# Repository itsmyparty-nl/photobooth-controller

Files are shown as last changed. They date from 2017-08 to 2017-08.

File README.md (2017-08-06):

# Photobooth Controller #

The hardware side of the photobooth

### What is this repository for? ###

* PCB Board & Corresponding Firmware to handle hardware buttons and lights for the photobooth 

### How do I get set up? ###

* Install Arduino
* Select correct library folder

### Contribution guidelines ###

* Writing tests
* Code review
* Other guidelines

### Who do I talk to? ###

* Patrick@itsmyparty.nl

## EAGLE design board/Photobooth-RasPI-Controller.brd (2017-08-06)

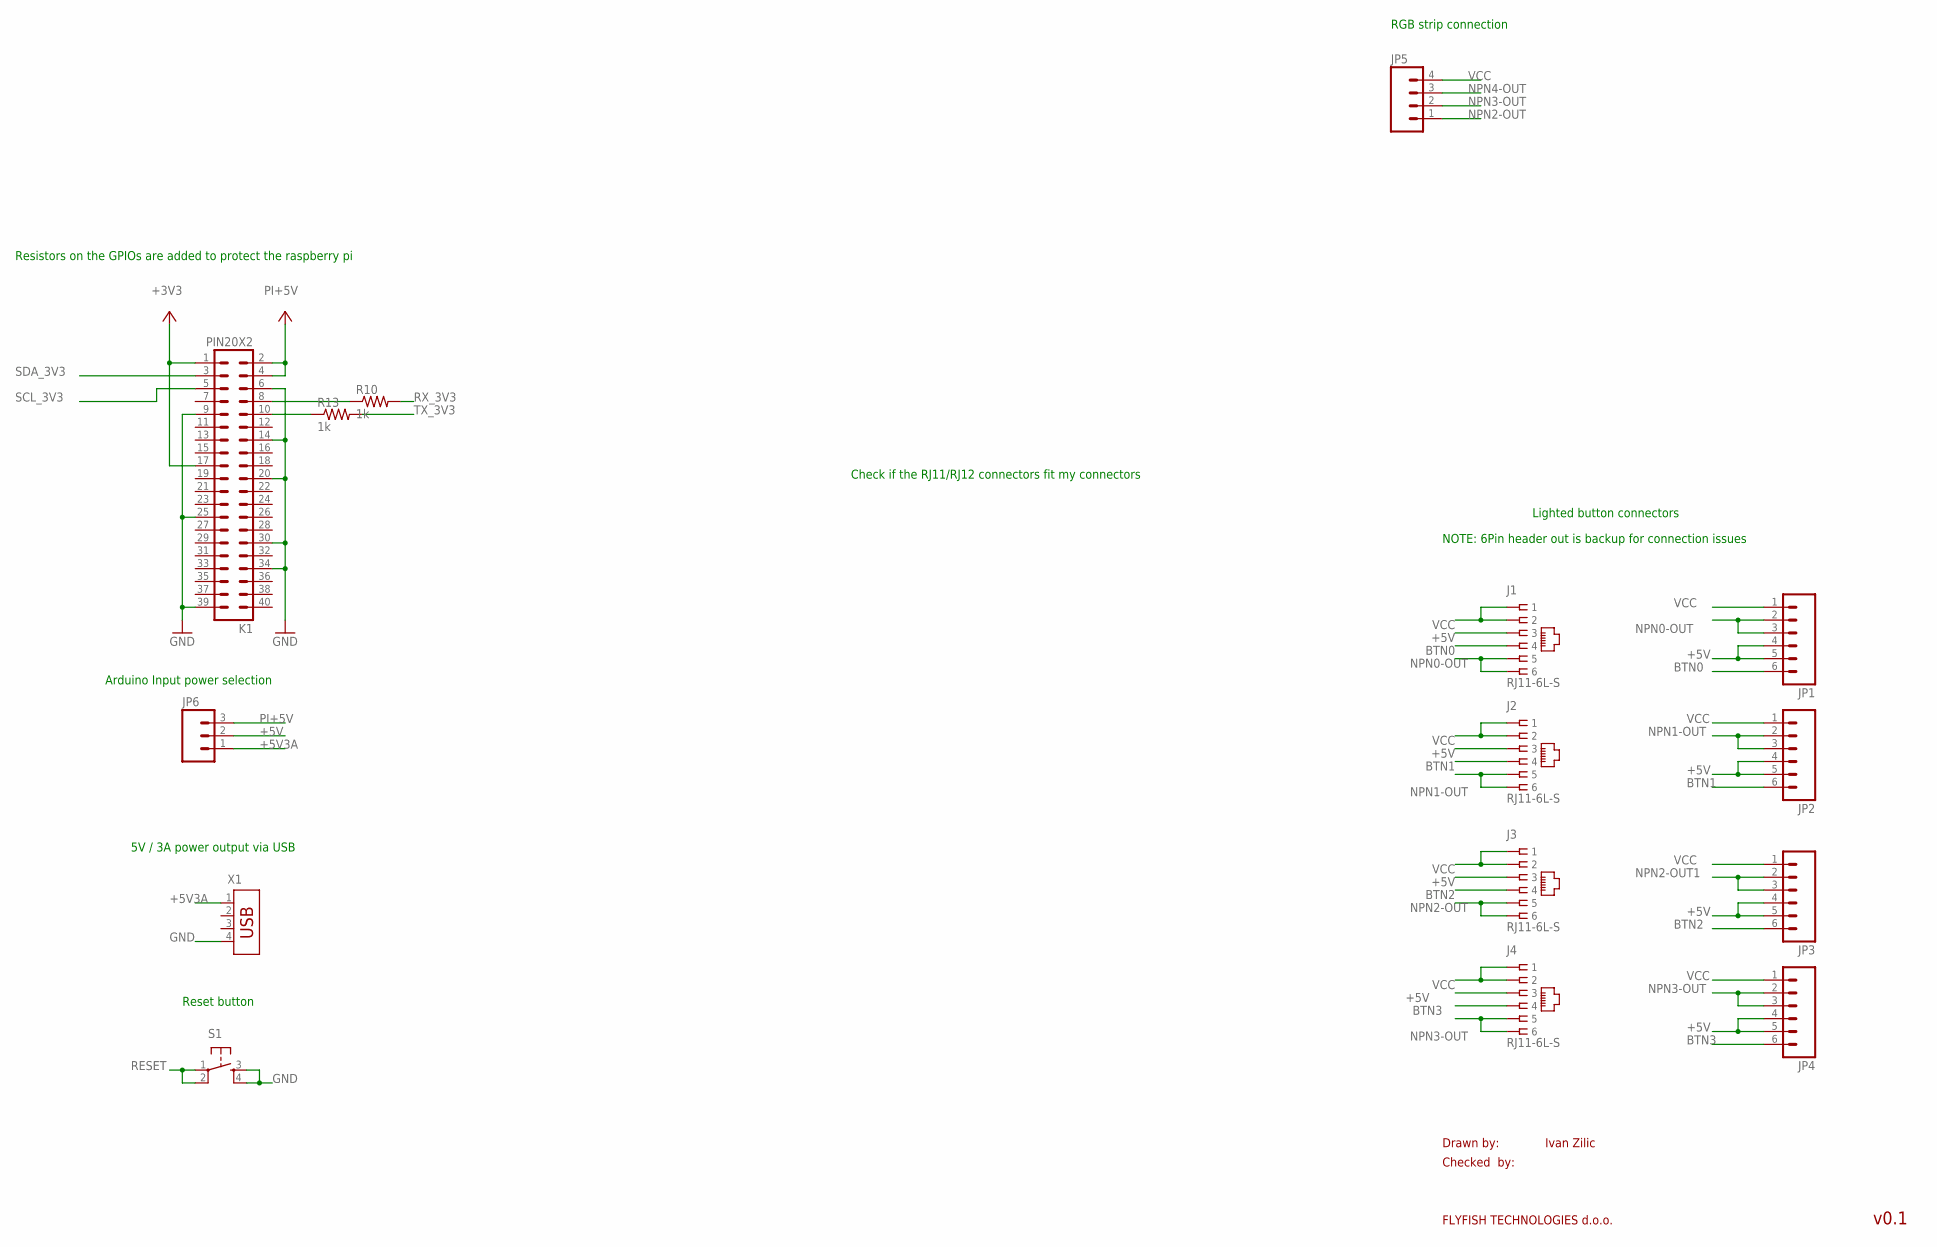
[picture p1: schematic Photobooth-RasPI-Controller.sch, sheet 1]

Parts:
J1, J2, J3, J4: RJ11-6L-S; RJ11-NO_SHIELD
JP1, JP2, JP3, JP4: M06LOCK; 1X06_LOCK
JP5: M04LOCK; 1X04_LOCK
JP6: M03LOCK; 1X03_LOCK
K1: PIN20X2; PIN_20X2
R10, R13: 1k; 0805
S1: TAC_SWITCHPTH; TACTILE-PTH
X1: USB-787616; USB

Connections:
+3V3: K1.1, K1.17; also elsewhere on the board
+5V: J1.3, J2.3, J3.3, J4.3, JP1.4, JP1.5, JP2.4, JP2.5, JP3.4, JP3.5, JP4.4, JP4.5, JP6.2; also elsewhere on the board
+5V3A: JP6.1, X1.1; also elsewhere on the board
BTN0: J1.4, JP1.6; also elsewhere on the board
BTN1: J2.4, JP2.6; also elsewhere on the board
BTN2: J3.4, JP3.6; also elsewhere on the board
BTN3: J4.4, JP4.6; also elsewhere on the board
GND: K1.6, K1.9, K1.14, K1.20, K1.25, K1.30, K1.34, K1.39, S1.3, S1.4, X1.4; also elsewhere on the board
unnamed: K1.8, R10.1
unnamed: K1.10, R13.1
NPN0-OUT: J1.5, J1.6, JP1.2, JP1.3; also elsewhere on the board
NPN1-OUT: J2.5, J2.6, JP2.2, JP2.3; also elsewhere on the board
NPN2-OUT: J3.5, J3.6, JP5.1; also elsewhere on the board
NPN2-OUT1: JP3.2, JP3.3
NPN3-OUT: J4.5, J4.6, JP4.2, JP4.3, JP5.2; also elsewhere on the board
NPN4-OUT: JP5.3; also elsewhere on the board
PI+5V: JP6.3, K1.2, K1.4
RESET: S1.1, S1.2; also elsewhere on the board
RX_3V3: R10.2; also elsewhere on the board
SCL_3V3: K1.5; also elsewhere on the board
SDA_3V3: K1.3; also elsewhere on the board
TX_3V3: R13.2; also elsewhere on the board
VCC: J1.1, J1.2, J2.1, J2.2, J3.1, J3.2, J4.1, J4.2, JP1.1, JP2.1, JP3.1, JP4.1, JP5.4; also elsewhere on the board

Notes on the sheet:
Drawn by:
Checked by:
FLYFISH TECHNOLOGIES d.o.o.
Ivan Zilic
v0.1
5V / 3A power output via USB
Resistors on the GPIOs are added to protect the raspberry pi
Check if the RJ11/RJ12 connectors fit my connectors
RGB strip connection
Lighted button connectors
NOTE: 6Pin header out is backup for connection issues
Arduino Input power selection
Reset button

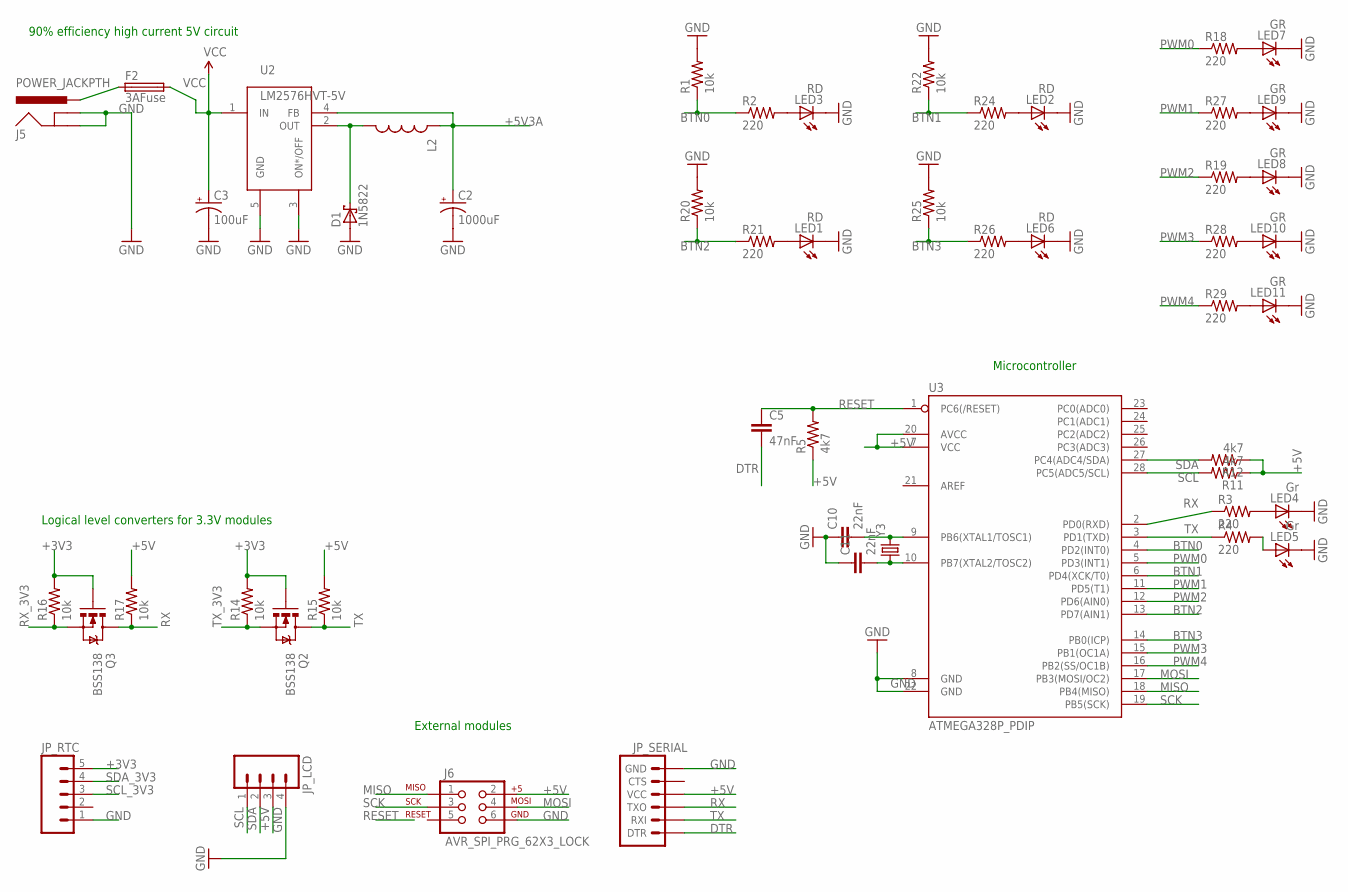
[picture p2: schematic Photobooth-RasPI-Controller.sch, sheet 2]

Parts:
C2: 1000uF; CPOL-RADIAL-1000UF-25V
C3: 100uF; CPOL-RADIAL-100UF-25V
C5: 47nF; CAP-PTH-SMALL
C10, C11: 22nF; CAP-PTH-SMALL
D1: 1N5822; C4111-15
F2: 3AFuse; LITTLEFUSE
J5: POWER_JACKPTH; POWER_JACK_PTH
J6: AVR_SPI_PRG_62X3_LOCK; 2X3_LOCK
JP_LCD: M04PTH; 1X04
JP_RTC: M05LOCK; 1X05_LOCK
JP_SERIAL: ARDUINO_SERIAL_PROGRAMLOCK; 1X06_LOCK
L2: INDUCTORRLB0912; RLB0912
LED1, LED2, LED3, LED6: RD; CHIP-LED0805
LED4, LED5: Gr; CHIP-LED0805
LED7, LED8, LED9, LED10, LED11: GR; CHIP-LED0805
Q2, Q3: BSS138; SOT23-3
R1, R14, R15, R16, R17, R20, R22, R25: 10k; 0805
R2, R3, R4, R18, R19, R21, R24, R26, R27, R28, R29: 220; 0805
R5, R11, R12: 4k7; 0805
U2: LM2576HVT-5V; LM2576
U3: ATMEGA328P_PDIP; DIL28-3
Y3: CRYSTALHC49UV; HC49U-V

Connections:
+3V3: JP_RTC.5, Q2.1 (G), Q3.1 (G), R14.2, R16.2; also elsewhere on the board
+5V: J6.2, JP_LCD.3, JP_SERIAL.4 (VCC), R5.1, R11.1, R12.1, R15.2, R17.2, U3.7 (VCC), U3.20 (AVCC); also elsewhere on the board
+5V3A: C2.+, L2.1, U2.4 (FB); also elsewhere on the board
BTN0: R1.1, R2.1, U3.4 (PD2(INT0)); also elsewhere on the board
BTN1: R22.1, R24.1, U3.6 (PD4(XCK/T0)); also elsewhere on the board
BTN2: R20.1, R21.1, U3.13 (PD7(AIN1)); also elsewhere on the board
BTN3: R25.1, R26.1, U3.14 (PB0(ICP)); also elsewhere on the board
DTR: C5.2, JP_SERIAL.1 (DTR)
GND: C2.-, C3.2 (-), C10.1, C11.1, D1.A, J5.GND, J5.GNDBREAK, J6.6, JP_LCD.4, JP_RTC.1, JP_SERIAL.6 (GND), LED1.C, LED2.C, LED3.C, LED4.C, LED5.C, LED6.C, LED7.C, LED8.C, LED9.C, LED10.C, LED11.C, R1.2, R20.2, R22.2, R25.2, U2.3 (ON*/OFF), U2.5 (GND), U3.8 (GND), U3.22 (GND); also elsewhere on the board
MISO: J6.1, U3.18 (PB4(MISO))
MOSI: J6.4, U3.17 (PB3(MOSI/OC2))
unnamed: C11.2, U3.10 (PB7(XTAL2/TOSC2)), Y3.1
unnamed: C10.2, U3.9 (PB6(XTAL1/TOSC1)), Y3.2
unnamed: D1.C, L2.2, U2.2 (OUT)
unnamed: LED7.A, R18.2
unnamed: LED8.A, R19.2
unnamed: LED1.A, R21.2
unnamed: LED2.A, R24.2
unnamed: LED6.A, R26.2
unnamed: LED9.A, R27.2
unnamed: LED10.A, R28.2
unnamed: LED11.A, R29.2
unnamed: F2.1, J5.PWR
unnamed: LED3.A, R2.2
unnamed: LED4.A, R3.2
unnamed: LED5.A, R4.2
PWM0: R18.1, U3.5 (PD3(INT1)); also elsewhere on the board
PWM1: R27.1, U3.11 (PD5(T1)); also elsewhere on the board
PWM2: R19.1, U3.12 (PD6(AIN0)); also elsewhere on the board
PWM3: R28.1, U3.15 (PB1(OC1A)); also elsewhere on the board
PWM4: R29.1, U3.16 (PB2(SS/OC1B)); also elsewhere on the board
RESET: C5.1, R5.2, U3.1 (PC6(/RESET)); also elsewhere on the board
RX: JP_SERIAL.3 (TXO), Q3.3 (D), R3.1, R17.1, U3.2 (PD0(RXD))
RX_3V3: Q3.2 (S), R16.1; also elsewhere on the board
SCK: J6.3, U3.19 (PB5(SCK))
SCL: JP_LCD.1, R11.2, U3.28 (PC5(ADC5/SCL))
SCL_3V3: JP_RTC.3; also elsewhere on the board
SDA: JP_LCD.2, R12.2, U3.27 (PC4(ADC4/SDA))
SDA_3V3: JP_RTC.4; also elsewhere on the board
TX: JP_SERIAL.2 (RXI), Q2.3 (D), R4.1, R15.1, U3.3 (PD1(TXD))
TX_3V3: Q2.2 (S), R14.1; also elsewhere on the board
VCC: C3.1 (+), F2.2, U2.1 (IN); also elsewhere on the board

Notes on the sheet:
Logical level converters for 3.3V modules
External modules
90% efficiency high current 5V circuit
Microcontroller

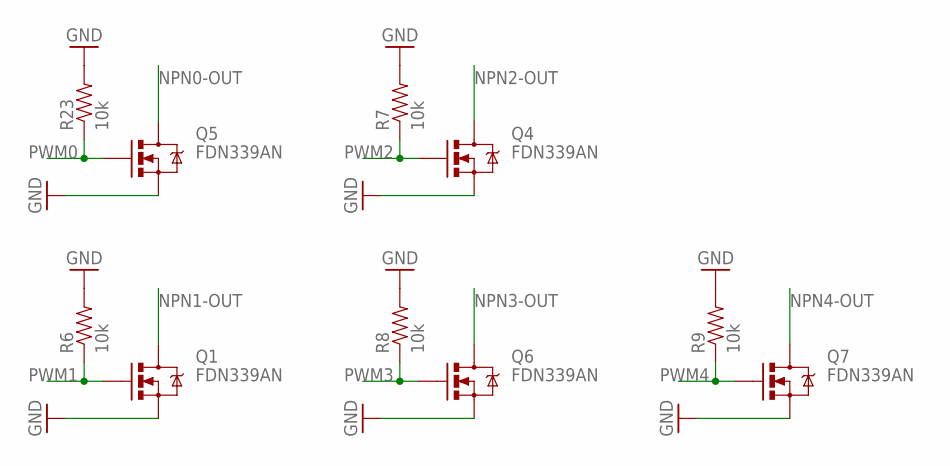
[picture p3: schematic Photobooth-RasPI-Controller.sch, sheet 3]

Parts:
Q1, Q4, Q5, Q6, Q7: FDN339AN; SOT23-3
R6, R7, R8, R9, R23: 10k; 0805

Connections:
GND: Q1.2 (S), Q4.2 (S), Q5.2 (S), Q6.2 (S), Q7.2 (S), R6.2, R7.2, R8.2, R9.2, R23.2; also elsewhere on the board
NPN0-OUT: Q5.3 (D); also elsewhere on the board
NPN1-OUT: Q1.3 (D); also elsewhere on the board
NPN2-OUT: Q4.3 (D); also elsewhere on the board
NPN3-OUT: Q6.3 (D); also elsewhere on the board
NPN4-OUT: Q7.3 (D); also elsewhere on the board
PWM0: Q5.1 (G), R23.1; also elsewhere on the board
PWM1: Q1.1 (G), R6.1; also elsewhere on the board
PWM2: Q4.1 (G), R7.1; also elsewhere on the board
PWM3: Q6.1 (G), R8.1; also elsewhere on the board
PWM4: Q7.1 (G), R9.1; also elsewhere on the board

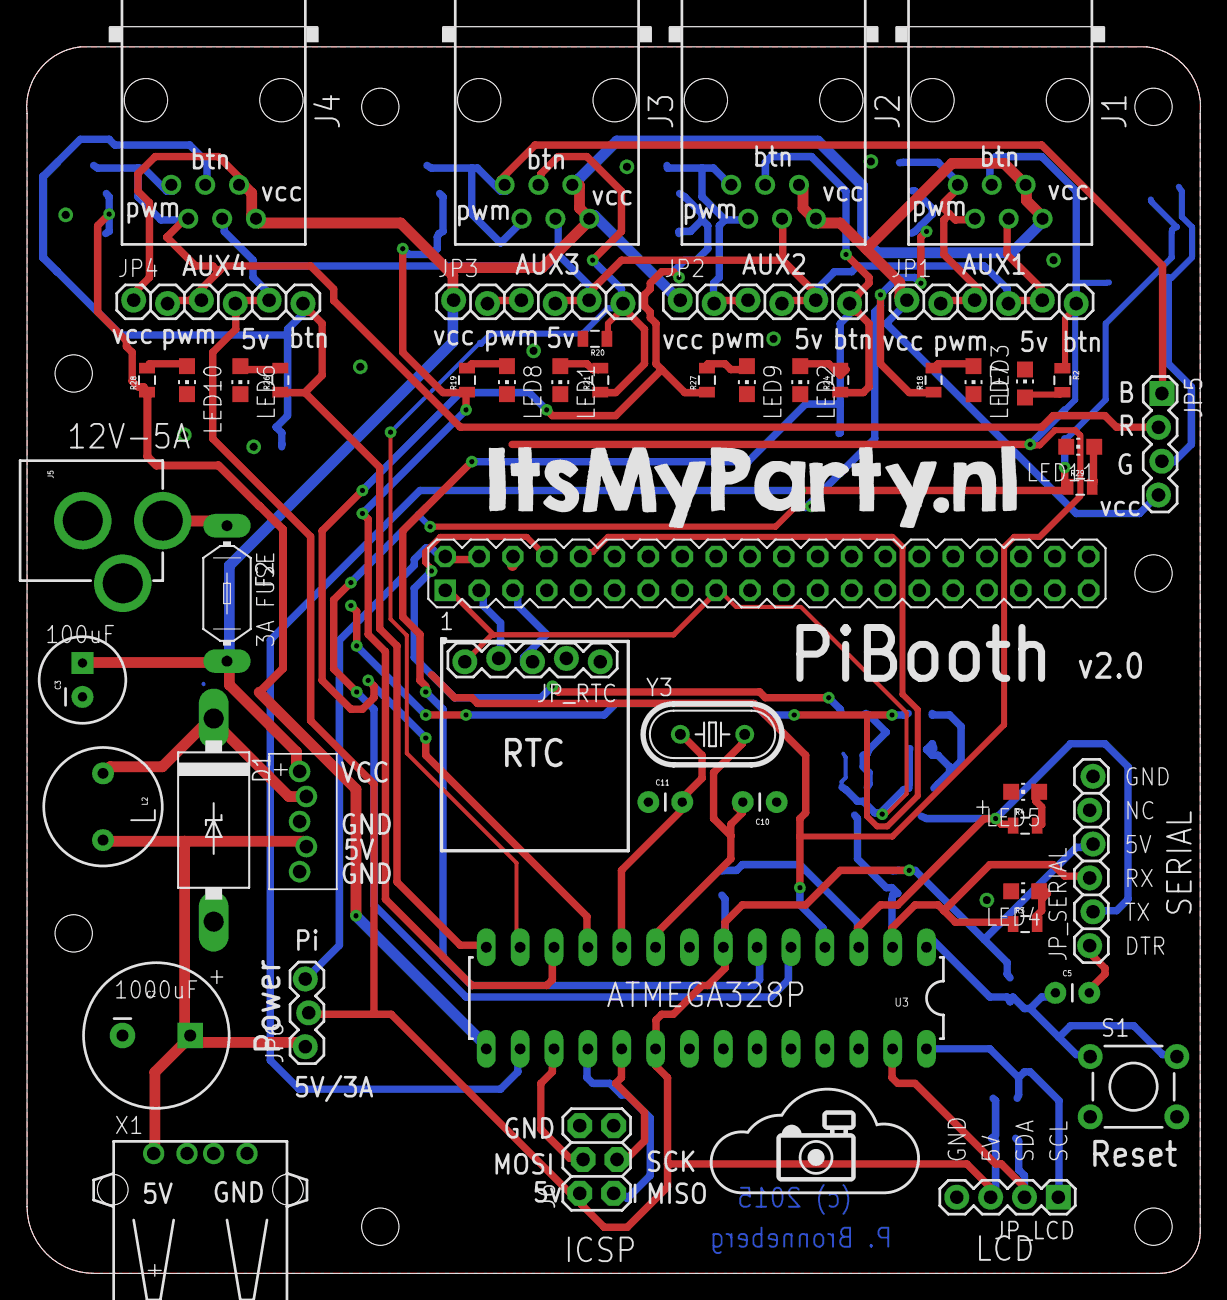
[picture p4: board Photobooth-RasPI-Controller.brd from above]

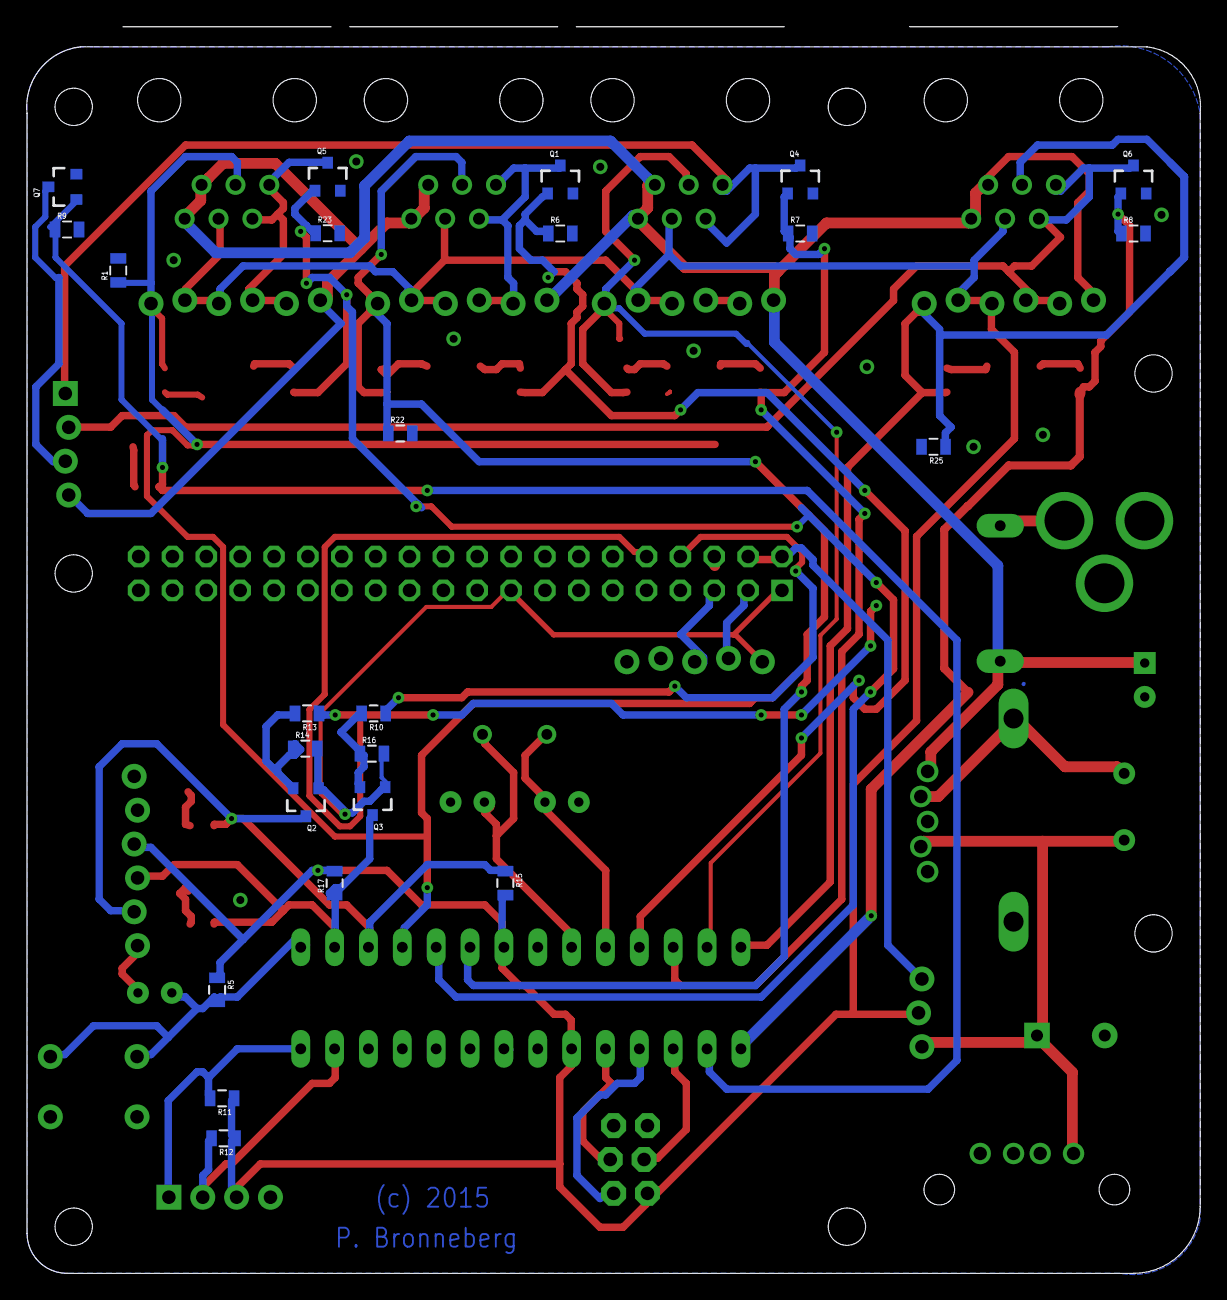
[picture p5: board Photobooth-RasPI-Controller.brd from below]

Board: 2 copper layers, 88.0 x 93.5 mm, 76 parts (24 on the bottom side), 51 nets.

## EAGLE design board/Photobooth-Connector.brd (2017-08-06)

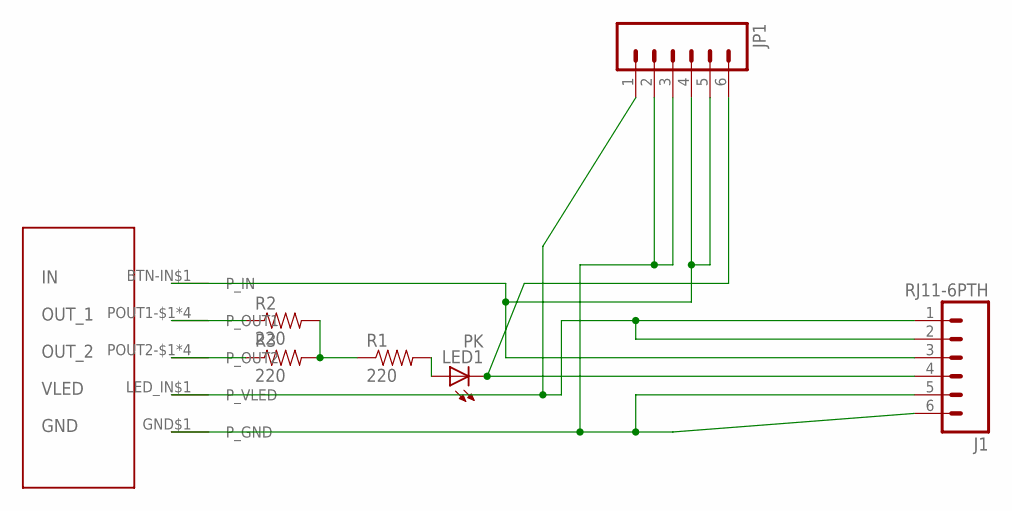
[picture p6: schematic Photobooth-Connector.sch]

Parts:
J1: RJ11-6PTH; RJ11-6
JP1: M06LOCK; 1X06_LOCK
LED1: PK; CHIP-LED0805
R1, R2, R3: 220; 0805
U$1: KERMIS_BUTTON; SLOT_DRILLED

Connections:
unnamed: J1.3, JP1.4, JP1.5, U$1.BTN-IN$1 (P_IN)
unnamed: J1.4, JP1.6, LED1.C
unnamed: R1.1, R2.2, R3.2
unnamed: LED1.A, R1.2
unnamed: J1.1, J1.2, JP1.1, U$1.LED_IN$1 (P_VLED)
unnamed: J1.5, J1.6, JP1.2, JP1.3, U$1.GND$1 (P_GND)
unnamed: R2.1, U$1.POUT1-$1 (P_OUT1), U$1.POUT1-$2 (P_OUT1), U$1.POUT1-$3 (P_OUT1), U$1.POUT1-$4 (P_OUT1)
unnamed: R3.1, U$1.POUT2-$1 (P_OUT2), U$1.POUT2-$2 (P_OUT2), U$1.POUT2-$3 (P_OUT2), U$1.POUT2-$4 (P_OUT2)

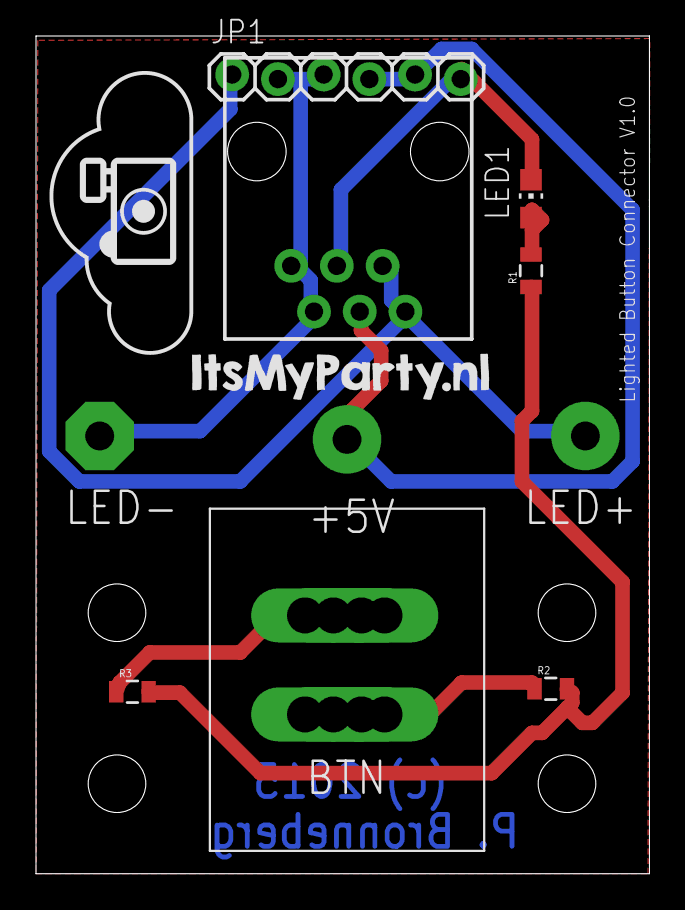
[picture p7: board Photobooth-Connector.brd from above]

Board: 2 copper layers, 34.1 x 46.5 mm, 7 parts (0 on the bottom side), 8 nets.

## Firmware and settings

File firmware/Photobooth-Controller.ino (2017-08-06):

// *** PhotoboothController ***
// Control the photobooth by supplying buttons which can be armed and released,
// which send commands to the application via a serial interface and the
// CmdMessenger library
// Based on the ArduinoController example

#include <CmdMessenger.h>  // CmdMessenger
#include <SoftTimer.h>
#include <Heartbeat.h>
#include <BlinkTask.h>
#include <SoftPwmTask.h>
#include <Dimmer.h>

// status heartbeat led variables 
const int ledPin            = 13;  // Pin of internal Led
bool ledState               = 1;   // Current state of Led

bool triggerBtnPushed = false;
bool printBtnPushed = false;
bool printTwiceBtnPushed = false;
bool powerBtnPushed = false;

#define INPUT_PIN_1 2
#define INPUT_PIN_2 4
#define INPUT_PIN_3 7
#define INPUT_PIN_4 8

/* In this demonstration a pulsating is implemented. */
#define OUT_PIN_1  3
#define OUT_PIN_2  5
#define OUT_PIN_3  6
#define OUT_PIN_4  9

#define triggerBtnLed  OUT_PIN_1
#define powerBtnLed  OUT_PIN_4
#define printBtnLed  OUT_PIN_2
#define printTwiceBtnLed  OUT_PIN_3

#define triggerBtnPin  INPUT_PIN_1
#define powerBtnPin  INPUT_PIN_4
#define printBtnPin  INPUT_PIN_2
#define printTwiceBtnPin  INPUT_PIN_3

Task buttonTaskTrigger(110, buttonReadTrigger);
Task buttonTaskPrint(80, buttonReadPrint);
Task buttonTaskPrintTwice(120, buttonReadPrintTwice);
Task buttonTaskPower(90, buttonReadPower);
Task commandHandlerTask(500, readSerial);

Heartbeat triggerLedTask(triggerBtnLed);
BlinkTask printLedTask(printBtnLed,1000);
BlinkTask printTwiceLedTask(printTwiceBtnLed,1000);
BlinkTask powerLedTask(powerBtnLed,1000);

//SoftPwmTask triggerLockedLedTask(triggerBtnLed);
//SoftPwmTask printLockedLedTask(printBtnLed);
//SoftPwmTask printTwiceLockedLedTask(printTwiceBtnLed);
//SoftPwmTask powerLockedLedTask(powerBtnLed);
//Dimmer triggerLockedDimmer(&triggerLockedLedTask, 1500);
//Dimmer printLockedDimmer(&printLockedLedTask, 1500);
//Dimmer printTwiceLockedDimmer(&printTwiceLockedLedTask, 1500);
//Dimmer powerLockedDimmer(&powerLockedLedTask, 1500);

// Attach a new CmdMessenger object to the default Serial port
CmdMessenger cmdMessenger = CmdMessenger(Serial);

// This is the list of recognized commands. These kcan be commands that can either be sent or received. 
// In order to receive, attach a callback function to these events
enum
{
  kAcknowledge,
  kError,
  kTrigger,
  kPrint,
  kPower,
  kPrepareControl,
  kReleaseControl,
  kPrintTwice,
  kLockControl,
  kUnlockControl,
  kInitialize
};

// Callbacks define on which received commands we take action
void attachCommandCallbacks()
{
  // Attach callback methods
  cmdMessenger.attach(OnUnknownCommand);
  cmdMessenger.attach(kPrepareControl, OnPrepareControl);
  cmdMessenger.attach(kReleaseControl, OnReleaseControl);
  cmdMessenger.attach(kLockControl, OnLockControl);
  cmdMessenger.attach(kUnlockControl, OnLockControl);
  cmdMessenger.attach(kInitialize, Initialize);
}

// Called when a received command has no attached function
void OnUnknownCommand()
{
  cmdMessenger.sendCmd(kError,"Command without attached callback");
}

// Initialize all controls to a ready state
void Initialize()
{
  // Remove all tasks, since the UDOO arduino has persistent state
  SoftTimer.remove(&buttonTaskPrintTwice);
  SoftTimer.remove(&printTwiceLedTask);
  SoftTimer.remove(&buttonTaskPrint);
  SoftTimer.remove(&printLedTask);
  SoftTimer.remove(&buttonTaskTrigger);
  SoftTimer.remove(&triggerLedTask);
  SoftTimer.remove(&buttonTaskPower);
  
  // Also stop all dimmers
  //triggerLockedDimmer.off();
  //powerLockedDimmer.off();
  //printLockedDimmer.off();
  //printTwiceLockedDimmer.off();
 
  //Set all pins low to check connections
  digitalWrite(OUT_PIN_1, LOW);
  digitalWrite(OUT_PIN_2, LOW);
  digitalWrite(OUT_PIN_3, LOW);
  digitalWrite(OUT_PIN_4, LOW);
}

// Callback function that sets led on or off
void OnLockControl()
{
  int control;
  // Read led state argument, interpret string as int
  control = cmdMessenger.readIntArg();
  switch (control)
  {
    case kTrigger:
      digitalWrite(triggerBtnLed, LOW);
      //triggerLockedDimmer.startPulsate();
      digitalWrite(triggerBtnLed, HIGH);
      break;
    case kPower:
      digitalWrite(powerBtnLed, LOW);
      //powerLockedDimmer.startPulsate();
      digitalWrite(powerBtnLed, HIGH); 
      break;
    case kPrint:
      digitalWrite(printBtnLed, LOW);
      //printLockedDimmer.startPulsate();
      digitalWrite(printBtnLed, HIGH);
      break;
    case kPrintTwice:
      digitalWrite(printTwiceBtnLed, LOW);
      //printTwiceLockedDimmer.startPulsate();
      digitalWrite(printTwiceBtnLed, HIGH);
      break;
    default:
      cmdMessenger.sendCmd(kError,"Unsupported button");
  }

  cmdMessenger.sendCmd(kAcknowledge,control);
}

void OnUnlockControl()
{
  int control;
  // Read led state argument, interpret string as int
  control = cmdMessenger.readIntArg();
  switch (control)
  {
    case kTrigger:
      //triggerLockedDimmer.off();
      digitalWrite(triggerBtnLed, LOW);
      break;
    case kPower:
      //powerLockedDimmer.off();
      digitalWrite(powerBtnLed, LOW);
      break;
    case kPrint:
      //printLockedDimmer.off();
      digitalWrite(printBtnLed, LOW);
      break;
    case kPrintTwice:
      //printTwiceLockedDimmer.off();
      digitalWrite(printTwiceBtnLed, LOW);
      break;
    default:
      cmdMessenger.sendCmd(kError,"Unsupported button");
  }

  cmdMessenger.sendCmd(kAcknowledge,control);
}

// Callback function that sets led on or off
void OnPrepareControl()
{
  int control;
  // Read led state argument, interpret string as int
  control = cmdMessenger.readIntArg();
  switch (control)
  {
    case kTrigger:
      SoftTimer.add(&buttonTaskTrigger);
      SoftTimer.add(&triggerLedTask);
      break;
    case kPower:
      SoftTimer.add(&buttonTaskPower);
      digitalWrite(powerBtnLed, HIGH);
      break;
    case kPrint:
      SoftTimer.add(&buttonTaskPrint);
      SoftTimer.add(&printLedTask);
      break;
    case kPrintTwice:
      SoftTimer.add(&buttonTaskPrintTwice);
      SoftTimer.add(&printTwiceLedTask);
      break;
    default:
      cmdMessenger.sendCmd(kError,"Unsupported button");
  }

  cmdMessenger.sendCmd(kAcknowledge,control);
}
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

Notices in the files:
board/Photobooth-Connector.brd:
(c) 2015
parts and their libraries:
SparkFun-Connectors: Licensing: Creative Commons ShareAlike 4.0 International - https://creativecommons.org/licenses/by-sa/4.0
